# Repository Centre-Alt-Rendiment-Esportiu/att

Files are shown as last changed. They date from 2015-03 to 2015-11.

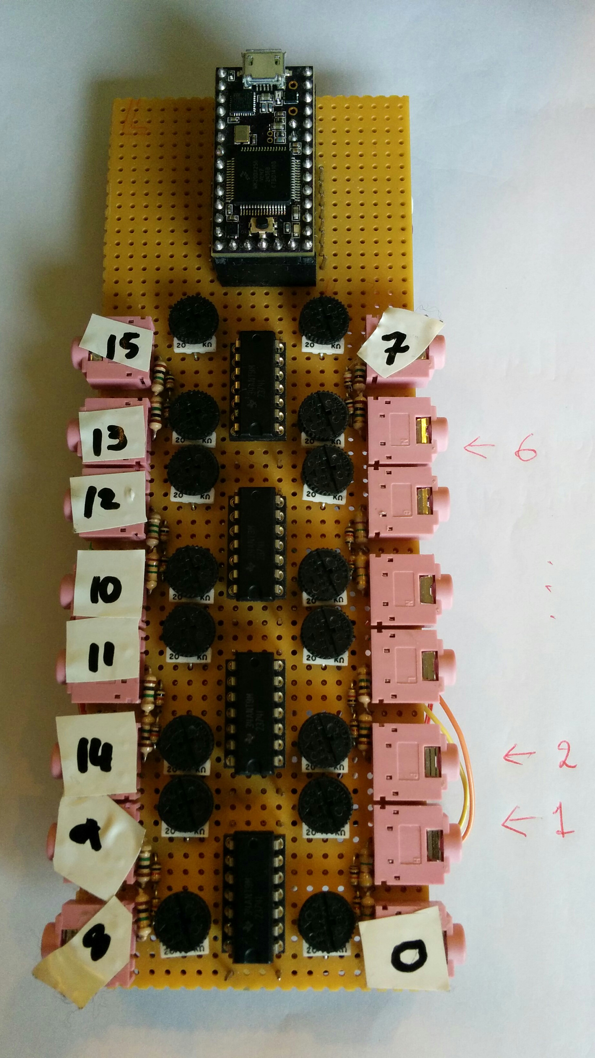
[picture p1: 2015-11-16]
docs/IMG_20151008_105158.jpg

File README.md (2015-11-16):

# Augmented Tennis Table

Augmented Tennis Table is a redesign/fork of PingPong++, a 1998 project of the Tangible Media Group that augmented a pingpong table with ball sensing and interactive projection. This repository contains all the files necessary to setup and run PingPong++.
The propose of this next step of Augmented Table Tennis is to approach it to high performance with specific needs of coaches and training demand based on the EU EXPERIMEDIA Project

* Explore how technology can enhance professional training in table tennis.
* Discover what kind of information is meaningful or too subtle to be directly detected.
* Design a prototype of a system which enables augmented feedback to both elite players and coaches.
*Test it and find requirements for a further version of the system

The experiment provides an automatic notation analysis system for table tennis based on the capture of the bouncing of the ball on the table through sound or vibration. The data obtained from the bouncing location and time is shown projected on the same table and/or a second screen. Statistics, game zones, accuracy, flight time or winning points, can be shown in real-time or after the game to analyse what happened. All the team can be involved in the discussion—athletes, coaches and technical and scientific staff—to help the process to be more efficient.
The way the data can be analysed will change forever the point of view of discussing the game of table tennis.

The experiment used focus group’s to co-create three basic scenarios where the technology could be applied:

* Target training:the scenario has two players (or one player and one assistant) where the trainee has to practice a particular kind of stroke returning the ball in a specific area for a certain amount of times. The area, the number of times and the repetitions of the exercise are set by the assistant. At the end of each repetition, information about the practice was shown on the table and on the screen. The stakeholder required to display a percentage of success, coded with a specific colour. The motivation behind this scenario is to quantify the precision of the player.
* Service Training: the scenario has the presence of one player, practicing the service. The system displays the hits on the table with a relative ID to show the order and the time differences between the bounces on the screen. The trainer sets the number of services to be practiced. The scenario has the goals of representing exactly where the ball is bouncing (difficult to be seen from the player perspective) and shorten the time between the first two bounces. The coach wants also to use it to experiment a hypothesis that he elaborated about associating different time differences according the kind of spin applied.
* Rally Point Patterns: the players play a rally (one point) and the system shows who wins it, and using lines and circles it should represent the situation of the point just played. It was agreed to use a gradient scale to colour the lines to code the time of the hits (from cold colours for older hits till warm colours for the recent ones). The goal of the scenario is to try to represent the gameplay of the players and make post-game analysis.

This first pilot opens new opportunities to share this information with TV in case of Live events or through colleagues and team using images and data. The way metadata is projected over the table or thru complementary screen will enhance the information of the game and will become and attractive asset for TV Broadcasting giving a new way of looking at table tennis in major competitions. Statistics, Accuracy rating, game areas or playing tendencies would be shown in teal time or at the end of the rally to give and augmented reality of the game for the spectators.
On the other hand the same capability could be used on the daily training process using this additional information to enrich the discussion between athletes and coaches and scientific staff that at the end of the day will mean increase the benefits on the learning curve of the team and the sport through augmented reality information.

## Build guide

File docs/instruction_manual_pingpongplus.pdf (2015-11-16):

# PingPong++

## Instruction Manual

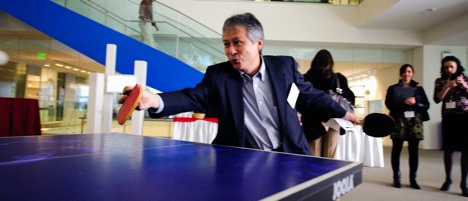
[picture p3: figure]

## Contents

0. Introduction | 3
0.1 Required Materials | 3
0.2 Software Requirements | 3
0.3 Technical Overview | 4
1. Hit Detection Circuitry | 5
1.1 Theory | 5
1.2 Parts | 5
1.3 Piezo Preparation | 6
1.4 Board Fabrication | 7
Installation | 7
2.1 Projector | 7
2.2 Table | 7

2.3 Connections | 8
2.4 Arduino | 8
3. Calibration | 10
4. Running | 12
4.1 Opening Koi Pond | 13
4.2 Present Mode | 13
4.3 Run Mode | 14

## 0. Introduction

PingPong++ is a ping pong table with projected visualizations that respond to locations of ball hits. Based on PingPongPlus, a Tangible Media Group project from 1998, PingPong++ was redesigned by Xiao Xiao and Michael Bernstein in spring 2010.

This document provides instructions for augmenting any standard ping pong table into PingPong++.

### 0.1 Required Materials

The following materials are necessary for PingPong++. The hit detection board and its parts are detailed in Section 1. Specific parts that we used in our installation are given in parentheses

- PingPong table
- Our custom circuit board (see Section 1)
- Arduino board (Decimila, Duemilanove or Uno.
- From Sparkfun: http://www.sparkfun.com/products/11021)
- Computer (Mac mini running OS X 10.6 Snow Leopard)
- USB cord to connect Arduino to computer
- Projector (Hitachi short throw CP-A100 placed on a pedestal)
- Gaffer tape to attach sensors to table

### 0.2 Software Requirements

To run PingPong++, you will need to install the following:

Image: Arduino (left); Gaffer tape (middle); Our projector (right)

- Arduino
- Processing
- Python 2.6
- serial, re, math, random, numpy, and scipy libraries for Python

The PongPong++ software package will include the following
- pingpongplusplus.ino (the Arduino file in the pingpongplusplus folder)
- koi pond (Processing visualization)
- calibration (Processing visualization to help with calibration)
- training.py (Python program to for calibration calculations)

### 0.3 Technical Overview

PingPong++ detects locations of hits on the table using 4 piezoelectric buzzers taped to the underside of each side of the table. Timing differences between pairs of piezo elements are used to calculate where the ball hit.

Our circuit conditions the signal from the piezos, which allows the Arduino board connected to the computer to calculate timing differences. These timing differences are then passed to a Processing visualization running on the computer via the serial port. The Processing visualization is projected on the table.

Image: A piezo buzzer

## 1. Hit Detection Circuitry

You will need to build a copy of our custom circuit for hit detection. Though we recommend using our PCB to simplify the process, We have used a breadboarded circuit and will provide instructions for those who prefer to build one.

### 1.1 Theory

The image below shows diagram of the circuit with capacitor and resistor values. The board includes 8 of this circuit, one for each piezo. The circuit works by first amplifying the piezo signal time 20. It then rectifies the signal so that the first “peaking” of the signal sets of the comparator to trigger a hit.

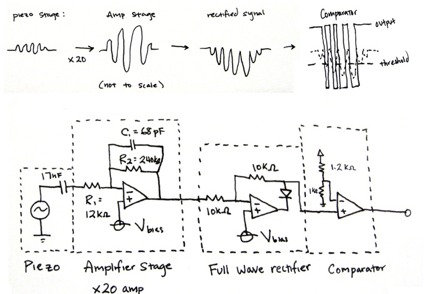
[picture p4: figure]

### 1.2 Parts

Through-hole components are given for breadboarding. Surface mount components are given for the packaging used in our PCB design.

- 8 piezo buzzers
- http://search.digikey.com/scripts/DkSearch/dksus.dll?Detail&name=102-1127-ND
- 8 audio jacks (PCB only) (http://search.digikey.com/scripts/DkSearch/dksus.dll?Detail&name=102-1127-ND)
- http://www.sparkfun.com/products/8032 (http://search.digikey.com/scripts/DkSearch/dksus.dll?Detail&name=102-1127-ND)
- 8 audio cords (PCB only) (http://search.digikey.com/scripts/DkSearch/dksus.dll?Detail&name=102-1127-ND)
- http://www.sparkfun.com/products/8566

- 8 68uF ceramic capacitors
- http://search.digikey.com/scripts/DkSearch/dksus.dll?Detail&name=478-1314-2-ND (surface mount)
- 6 TLV2374 Op-amps
- http://search.digikey.com/scripts/DkSearch/dksus.dll?Detail&name=296-12221-5-ND (through hole)
- http://search.digikey.com/scripts/DkSearch/dksus.dll?Detail&name=296-11967-1-ND (surface mount)
- 8 diodes 1N4148
- http://search.digikey.com/scripts/DkSearch/dksus.dll?Detail&name=1N4148FS-ND (through hole)
- http://search.digikey.com/scripts/DkSearch/dksus.dll?Detail&name=1N4148WTCT-ND (surface mount)
- 18 10 K-Ohm, 1% tolerance resistors (1% tolerance important)
- http://search.digikey.com/scripts/DkSearch/dksus.dll?Detail&name=PPC10.0KYCT-ND (through hole)
- http://search.digikey.com/scripts/DkSearch/dksus.dll?Detail&name=P10.0KCCT-ND (surface mount)
- 8 12 K-Ohm resistors
- http://search.digikey.com/scripts/DkSearch/dksus.dll?Detail&name=P12KBACT-ND (through hole)
- http://search.digikey.com/scripts/DkSearch/dksus.dll?Detail&name=P12KADCT-ND (surface mount)
- 8 240 K-Ohm resistors
- http://search.digikey.com/scripts/DkSearch/dksus.dll?Detail&name=PPCQJ240KCT-ND (through hole)
- http://search.digikey.com/scripts/DkSearch/dksus.dll?Detail&name=P240KACT-ND (surface mount)
- 1 1.2 K-Ohm resistor
- http://search.digikey.com/scripts/DkSearch/dksus.dll?Detail&name=P1.2KBACT-ND (through hole)
- http://search.digikey.com/scripts/DkSearch/dksus.dll?Detail&name=P1.2KACT-ND (surface mount)
- 1 1 K-Ohm resistor
- http://search.digikey.com/scripts/DkSearch/dksus.dll?Detail&name=PPC1.0KW-1CT-ND (through hole)
- http://search.digikey.com/scripts/DkSearch/dksus.dll?Detail&name=541-1.0KACT-ND (surface mount)
- Male headers

### 1.3 Piezo Preparation

The piezos must be prepared so that they can connect to the board. For the breadboard, the two ends of the piezos can simply be soldered to two pieces of wires between 3-6 feet long.

For the PCB, each piezo must connect to one end of an audio cable. To do so, cut off the audio jack from one end and strip the cable to expose the wires within. Solder the red wire of the piezo to the red and white wires in the cable and the black wire of the piezo to the yellow wire in the cable.

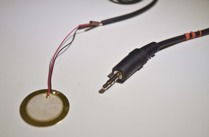
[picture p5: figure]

### 1.4 Board Fabrication

Here is an image of the board with one piezo plugged in.

## Installation

### 2.1 Projector

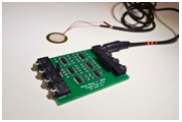
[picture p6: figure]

Our Hitachi projector is placed on a stand 5-feet (1.52m) tall so that it projects down onto the ping pong table. The distance between the stand and the table is about 3-feet but will need to be adjusted for specific situations.

Connect the projector to the computer and run the Calibration program in Processing. Position the projector such that the gray area of the program covers the entire ping pong table. The screen resolution of the computer may have to be adjusted for this.

### 2.2 Table

We attached piezos to the underside of the table using gaffer tape. 4 piezos are placed on each side in the configuration described in the figure. The piezo cables can be taped to the bottom of the table without interfering with the sensing and should be to avoid clutter. We ran the cables to one side of the table and attached them to legs of the table as in the image.

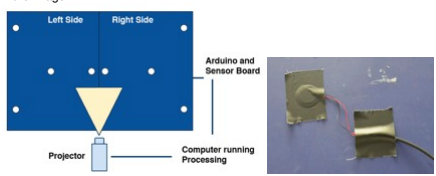
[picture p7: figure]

### 2.3 Connections

- Plug the sensor board into the Arduino according to the image
- Plug the 4 audio cables on the two sides of the table to the audio jacks on the two sides of the board. Make sure the left side and right side of the piezos and of the board match. Left and right are defined by the system configuration image.
- Connect the Arduino board and the computer with the USB cable

### 2.4 Arduino

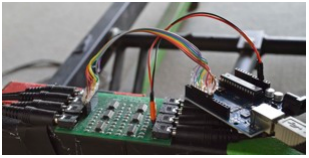
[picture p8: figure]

We need to verify that Arduino is receiving data from serial with the following steps. Your Arduino should be connected to your computer via USB when you do this.

1. Open the Arduino program
2. Go to Tools > Board and make sure the correct Arduino board is selected. Here weʼre using an Arduino UNO

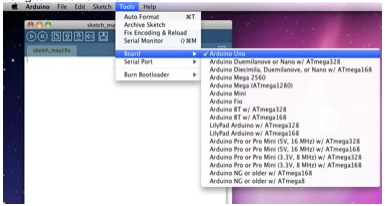
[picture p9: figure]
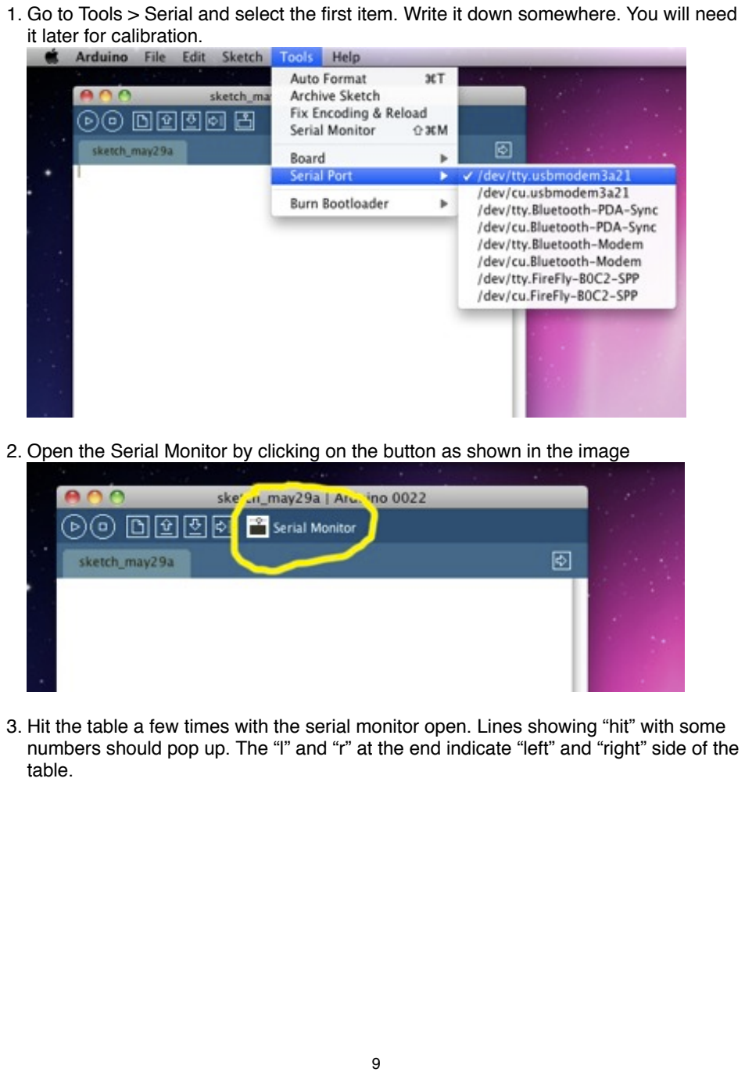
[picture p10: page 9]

1. Go to Tools > Serial and select the first item. Write it down somewhere. You will need it later for calibration.
2. Open the Serial Monitor by clicking on the button as shown in the image
3. Hit the table a few times with the serial monitor open. Lines showing “hit” with some numbers should pop up. The “l” and “r” at the end indicate “left” and “right” side of the table.

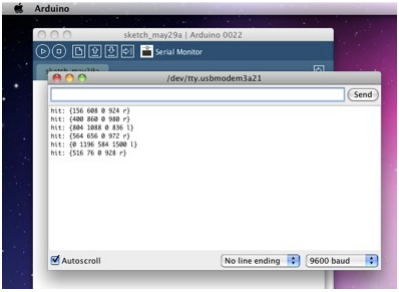
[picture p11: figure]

If everything works according to described, your computer is now receiving hit data from the Arduino! If nothing show up on the serial monitor when you hit the table, something is probably not connected properly.

## 3. Calibration

The calibration works by asking you to drop the ball at 20 points on each side of the table. The Calibration visualization shows you where to drop the balls.

Open Processing and run the Calibration visualization. See section 4 for instructions on how to run a program in Processing.

On another screen, you will run the Python program training.py to calibrate. Before running it, open it in a text editor program like TextEdit and change the port to what you copied from the Serial setting in Arduino. In our case, we are going to replace the highlighted line in the image with the following:

PORT = '/dev/tty.usbmodem3a21' # FOR MAC

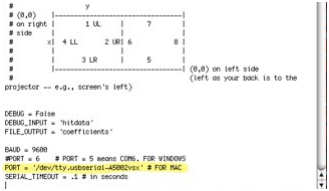
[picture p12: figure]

Now, open a terminal window and cd to where training.py is (we have it on the desktop). Type python2.6 training.py to run it.

It will ask you whether you want to calibrate the left, right or both sides. Press the key for your selection and press enter. Then follow the directions the script gives you.

For each point, it will ask you to drop the ball 5 times. For best results, vary how hard you drop the ball for each of the 5 drops. Start with light drops and gradually increase the strength it hits the table.
At the end of 5 repetitions, it will ask whether you want to do that point again or move on. If your ball accidentally bounced in a wrong place, you can press “r” to repeat that point. Otherwise, hit enter to continue.

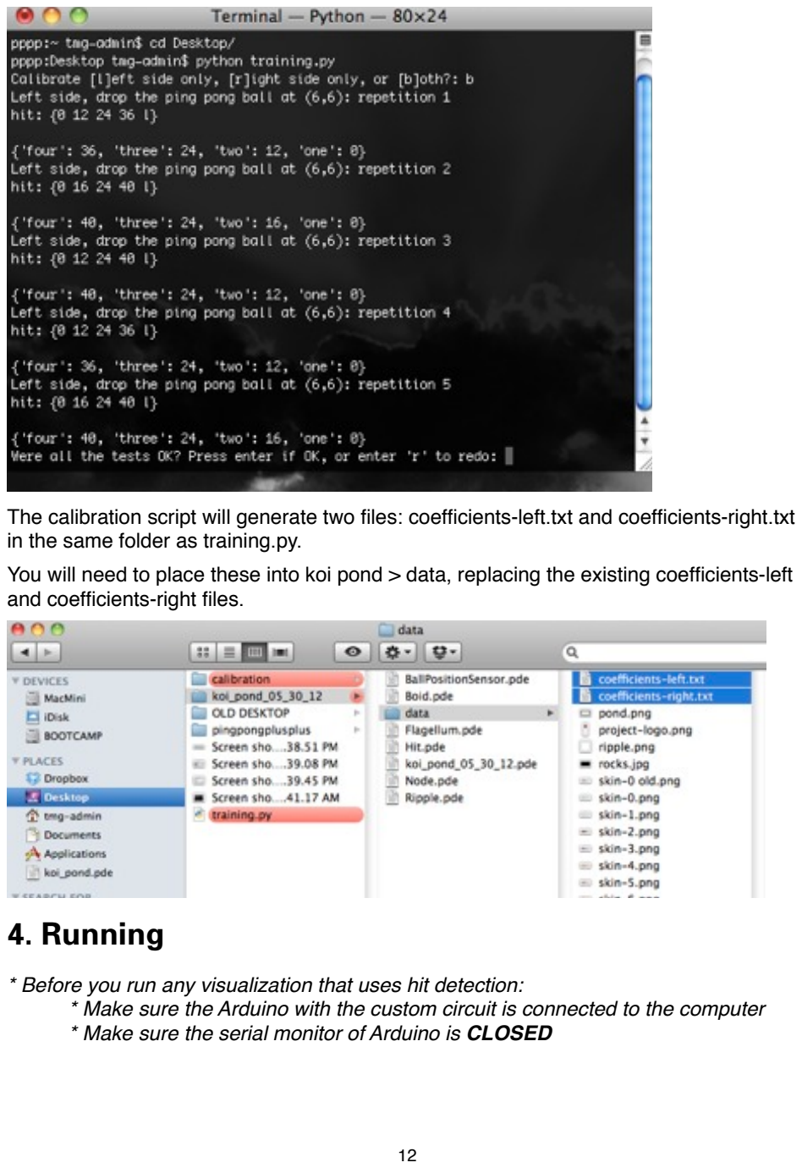
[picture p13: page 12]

The calibration script will generate two files: coefficients-left.txt and coefficients-right.txt in the same folder as training.py.
You will need to place these into koi pond > data, replacing the existing coefficients-left and coefficients-right files.

## 4. Running

* Before you run any visualization that uses hit detection:
* Make sure the Arduino with the custom circuit is connected to the computer * Make sure the serial monitor of Arduino is CLOSED

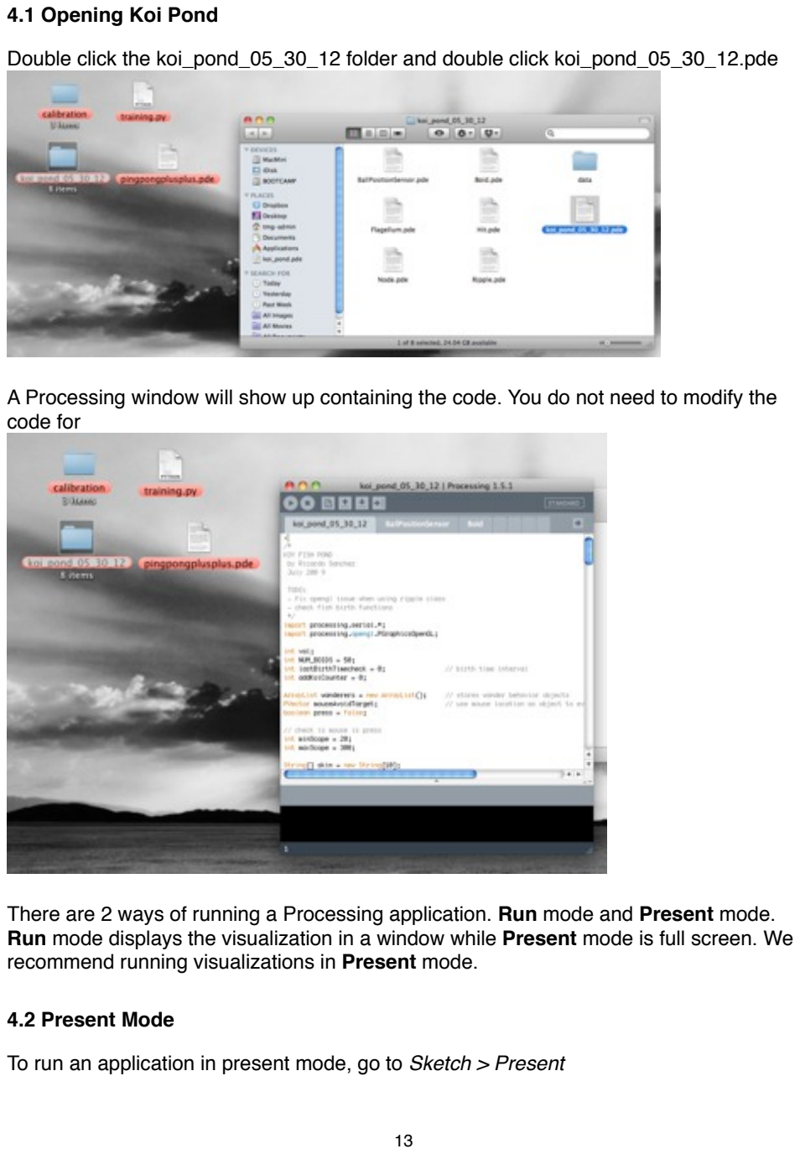
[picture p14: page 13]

### 4.1 Opening Koi Pond

Double click the koi_pond_05_30_12 folder and double click koi_pond_05_30_12.pde

A Processing window will show up containing the code. You do not need to modify the code for

There are 2 ways of running a Processing application. Run mode and Present mode. Run mode displays the visualization in a window while Present mode is full screen. We recommend running visualizations in Present mode.

### 4.2 Present Mode

To run an application in present mode, go to Sketch > Present

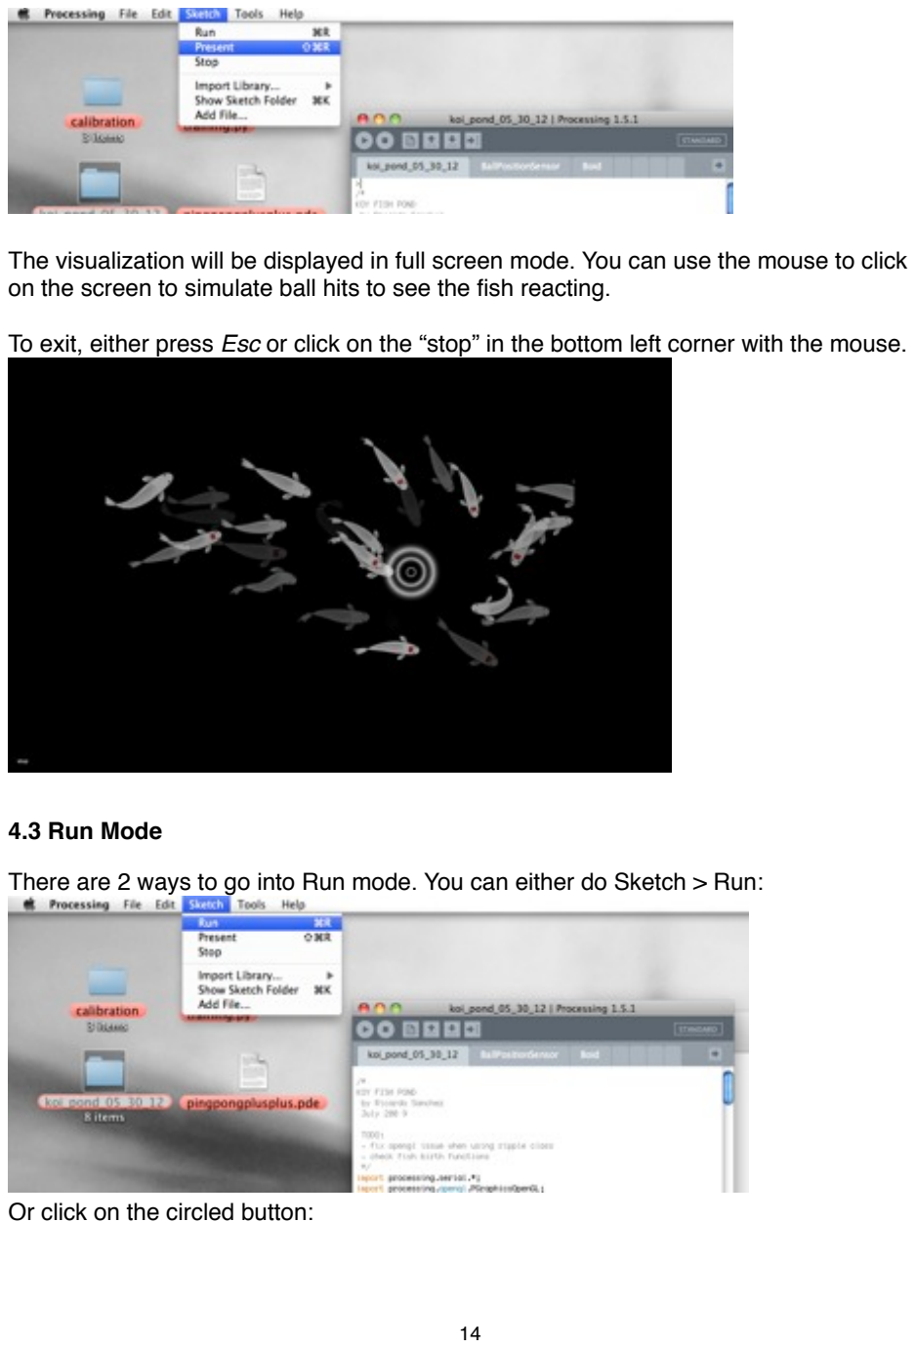
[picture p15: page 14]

The visualization will be displayed in full screen mode. You can use the mouse to click on the screen to simulate ball hits to see the fish reacting.

To exit, either press Esc or click on the “stop” in the bottom left corner with the mouse.

### 4.3 Run Mode

There are 2 ways to go into Run mode. You can either do Sketch > Run:

Or click on the circled button:

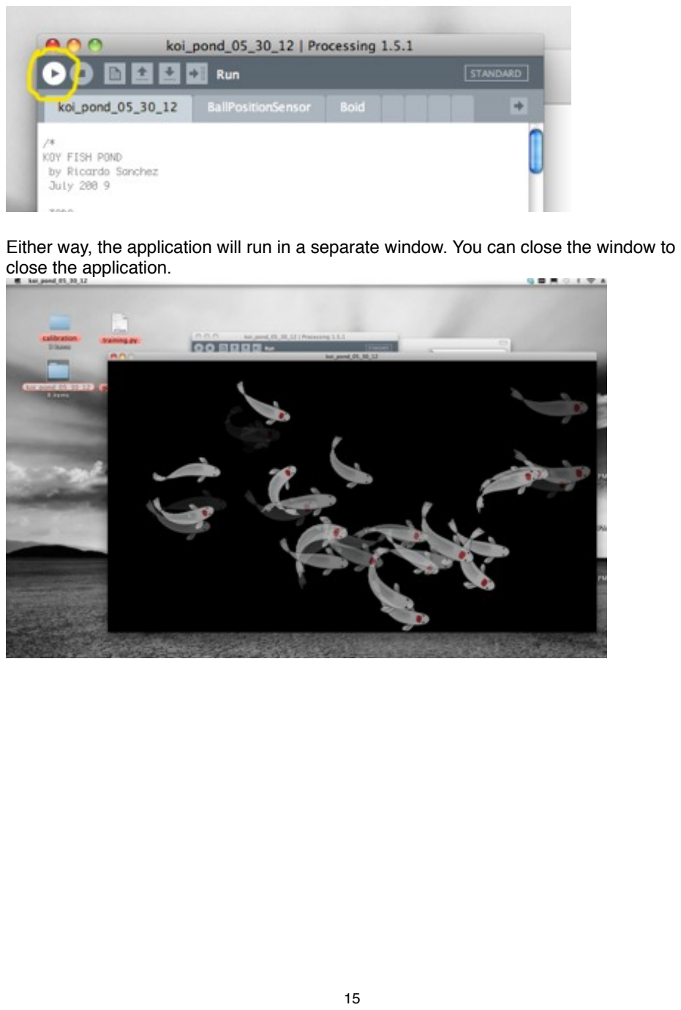
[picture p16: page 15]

Either way, the application will run in a separate window. You can close the window to close the application.

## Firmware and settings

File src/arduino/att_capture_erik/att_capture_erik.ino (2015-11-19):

/*
 * Original PingPong++
 * -------------
 * By Michael Bernstein (msbernst@mit.edu) and Xiao Xiao (x_x@mit.edu)
 *
 * Augmented Table Tennis
 * -------------
 * By Andrea Amodeo and Erik Einebrant
 */
 
// Constants
const int THRESHOLD = 30;
const int SENSOR_COUNT = 7;
//NOTE: There are 8 but for the time being we only use 7 as this is more compatible with available software

struct Hit {
  unsigned long timings[SENSOR_COUNT];
  int volumes[SENSOR_COUNT];
  
  unsigned long startTime;
  char side;
  boolean reported;  // have we sent it off via serial yet?
};

/*struct Hit {
  unsigned long upperLeft;
  unsigned long upperRight;
  unsigned long lowerLeft;
  unsigned long lowerRight;
  unsigned long centerLeft;
  unsigned long centerUp;
  unsigned long centerRight;
  unsigned long startTime;
  char side;
  boolean reported;  // have we sent it off via serial yet?
};*/

//Pin mapping of Teensy
int rightPins[] = {
  A8, A9, A10, A11, A12, A13, A14, /*A15*/}; // clockwise from top left
int leftPins[] = {
  A0, A1, A2, A3, A4, A5, A6, /*A7*/}; // clockwise from top left

const unsigned long NO_RECORD = -1;
const unsigned long TIMEOUT_BETWEEN_HITS = 300000; // in millis
const char LEFT = 'l';
const char RIGHT = 'r';

Hit curHit = { 
  NO_RECORD, NO_RECORD, NO_RECORD, NO_RECORD, NO_RECORD, NO_RECORD, NO_RECORD, NO_RECORD, LEFT, false};

void setup() {
  Serial.begin(115200);
}

/*void setup() {
  Serial.begin(115200);
  for (int i = 0; i < 7; i++) {
    int pinNumber = leftPins[i];
    pinMode(pinNumber, INPUT);
    pinNumber = rightPins[i];
    pinMode(pinNumber, INPUT);
  }
}*/

void loop() {
  //delay(5);
  readPins(leftPins, LEFT);
  readPins(rightPins, RIGHT);
  
  //Serial.println(curHit.volumes[0]);
  
  if (isCompleteHit(&curHit) && !curHit.reported) {
    // print the current hit status
    Serial.print("hit: {");
    for(int i = 0; i < SENSOR_COUNT; i++){
      Serial.print(curHit.timings[i]);
      /*Serial.print(":");
      Serial.print(curHit.volumes[i]);*/
      Serial.print(" ");
    }
    Serial.print(curHit.side);
    Serial.println("}");
    
    curHit.reported = true;
  }
  
  if(hitTimedOut()) {
    // create a new hit
    Hit newHit;
    for(int i = 0; i < SENSOR_COUNT; i++){
      newHit.timings[i] = NO_RECORD;
      newHit.volumes[i] = NO_RECORD;
    }
    
    newHit.side = LEFT;
    newHit.startTime = NO_RECORD;
    newHit.reported = false;
    
    curHit = newHit;
  }
}

/*void loop() {
  readPins(leftPins, LEFT);
  readPins(rightPins, RIGHT);
  
  if (isCompleteHit(&curHit) && !curHit.reported) {
    // print the current hit status
    Serial.print("hit: {");
    Serial.print(curHit.upperLeft);
    Serial.print(" ");
    Serial.print(curHit.upperRight);
    Serial.print(" ");
    Serial.print(curHit.lowerRight);
    Serial.print(" ");
    Serial.print(curHit.lowerLeft);
    Serial.print(" ");
    Serial.print(curHit.centerLeft);
    Serial.print(" ");
    Serial.print(curHit.centerUp);
    Serial.print(" ");
    Serial.print(curHit.centerRight);
    Serial.print(" ");
    Serial.print(curHit.side);
    Serial.println("}");
    
    curHit.reported = true;
  }

  if (hitTimedOut()) {
    // create a new hit
    Hit newHit;
    newHit.upperLeft = newHit.upperRight = newHit.lowerLeft = newHit.lowerRight = newHit.centerLeft = newHit.centerUp = newHit.centerRight = NO_RECORD;
    newHit.side = LEFT;
    newHit.startTime = NO_RECORD;
    newHit.reported = false;
    
    curHit = newHit;
  }
}*/

/*
 * For the list of one sides pins, see if any of them is detecting an analog reading above the threshold
 * and if so, report a hit with side and detection time
 */
void readPins(int* pinList, char curSide) {
  for (int i = 0; i < SENSOR_COUNT; i++) {
    int pinNumber = pinList[i];
    int pinValue = analogRead(pinNumber);
    //Serial.println(pinValue);
    if (pinValue >= THRESHOLD) {
      unsigned long detectionTime = micros();
      if (curHit.startTime == NO_RECORD) {
        curHit.startTime = detectionTime;
        curHit.side = curSide;
      }
      // add this data to the existing hit
      updateCorner(pinNumber, curSide, detectionTime, pinValue, pinList);
     }
  }
}

/*
 * Looks at each pin on the side to see if it is LOW (e.g., registered a hit) 
 * and updates the Hit data structure if so.
 */
/*void readPins(int* pinList, char curSide) {
  for (int i = 0; i < 7; i++) {
    int pinNumber = pinList[i];
    int pinValue = digitalRead(pinNumber);
    if (pinValue == LOW) {
      unsigned long detectionTime = micros();
      if (curHit.startTime == NO_RECORD) {
        curHit.startTime = detectionTime;
        curHit.side = curSide;
      }
      // add this data to the existing hit
      updateCorner(pinNumber, curSide, detectionTime, pinList);
     }
  }
}*/

/*
 * Updates the current hit data structure in the correct corner, given the pin number
 */
void updateCorner(int pinNumber, char curSide, unsigned long detectionTime, int pinValue, int* sidePins){
  for(int i = 0; i < SENSOR_COUNT; i++){
    if(pinNumber == sidePins[i] && curHit.timings[i] == NO_RECORD){
      curHit.timings[i] = detectionTime - curHit.startTime;
      curHit.volumes[i] = pinValue;
    }
  }
}

/*
 * Updates the current hit data structure in the correct corner, given the pin number
 */
/*void updateCorner(int pinNumber, char curSide, unsigned long detectionTime, int* sidePins) {

  if (pinNumber == sidePins[0] && curHit.upperLeft == NO_RECORD) {
    curHit.upperLeft = detectionTime - curHit.startTime;
  }
  else if (pinNumber == sidePins[1] && curHit.upperRight == NO_RECORD) {
    curHit.upperRight = detectionTime - curHit.startTime;
  }
  else if (pinNumber == sidePins[2] && curHit.lowerRight == NO_RECORD) {
    curHit.lowerRight = detectionTime - curHit.startTime;
  }
  else if (pinNumber == sidePins[3] && curHit.lowerLeft == NO_RECORD) {
    curHit.lowerLeft = detectionTime - curHit.startTime;
  }
  else if (pinNumber == sidePins[4] && curHit.centerLeft == NO_RECORD) {
    curHit.centerLeft = detectionTime - curHit.startTime;
  }
  else if (pinNumber == sidePins[5] && curHit.centerUp == NO_RECORD) {
    curHit.centerUp = detectionTime - curHit.startTime;
  }
  else if (pinNumber == sidePins[6] && curHit.centerRight == NO_RECORD) {
    curHit.centerRight = detectionTime - curHit.startTime;
  }
}*/

boolean hitTimedOut() {
  unsigned long time_since = micros() - curHit.startTime;
  boolean timed_out = (time_since >= TIMEOUT_BETWEEN_HITS);
  return (curHit.startTime == NO_RECORD || timed_out);
}

boolean isCompleteHit(struct Hit *hit) {
  boolean isHit = true;
  for(int i = 0; i < SENSOR_COUNT; i++){
    isHit = isHit && hit->timings[i] != NO_RECORD;
  }
  return isHit;
}

/*boolean isCompleteHit(struct Hit *hit) {
  return hit->upperLeft != NO_RECORD && hit->upperRight != NO_RECORD && hit->lowerRight != NO_RECORD && hit->lowerLeft != NO_RECORD && hit->centerLeft != NO_RECORD && hit->centerUp != NO_RECORD && hit->centerRight != NO_RECORD;
}*/

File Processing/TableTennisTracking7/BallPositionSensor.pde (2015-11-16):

 import matrixMath.*;

import processing.serial.*;

class BallPositionSensor {
  boolean debug = false;
  int TABLE_WIDTH = 60;   // inches
  int TABLE_HEIGHT = 54;  // inches
  int SENSOR_COUNT = 7;
  
  Serial arduinoSerial;
  matrixMath mc1_l, mc2_l, mc3_l, mc4_l, mc5_l, mc6_l, mc7_l, mc1_r, mc2_r, mc3_r, mc4_r, mc5_r, mc6_r, mc7_r;
  matrixMath[] mc_l[SENSOR_COUNT];
  matrixMath[] mc_r[SENSOR_COUNT];
  
  BallPositionSensor(PApplet applet, String portName, String coefficientFileLeft, String coefficientFileRight) {
    importCoeffs(coefficientFileLeft, false); // "../../coefficients-left.txt"
    importCoeffs(coefficientFileRight, true); // "../../coefficients-right.txt"
    arduinoSerial = new Serial(applet, portName, 115200);
  }

  void importCoeffs(String coefficientFile, boolean isRightSide) {
    String[] coeffs = loadStrings(coefficientFile);
    int sensorSum = 0;
    for(int s = 1; s <= SENSOR_COUNT; s++){
      sensorSum += s;
    }
    
    float[][][] coeffs = new float[SENSOR_COUNT][2][sensorSum];

    /*float[][] coeffs1 = new float[2][sensorSum];
    float[][] coeffs2 = new float[2][sensorSum];
    float[][] coeffs3 = new float[2][sensorSum];
    float[][] coeffs4 = new float[2][sensorSum];
    float[][] coeffs5 = new float[2][sensorSum];
    float[][] coeffs6 = new float[2][sensorSum];
    float[][] coeffs7 = new float[2][sensorSum];*/
    
    for(int i = 0; i < sensorSum; i++){
      for(int s = 0; s < SENSOR_COUNT; s++){
        int curSide = int(s >= SENSOR_COUNT);
        coeffs[s][curSide][i] = float(coeffs[sensorSum * s + i]);
      }
    }
    
    /*for (int i = 0; i < 28; i++) {
      coeffs1[0][i] = float(coeffs[i]);
      coeffs2[0][i] = float(coeffs[sensorSum * 1 + i]);
      coeffs3[0][i] = float(coeffs[sensorSum * 2 + i]);
      coeffs4[0][i] = float(coeffs[sensorSum * 3 + i]);
      coeffs5[0][i] = float(coeffs[sensorSum * 4 + i]);
      coeffs6[0][i] = float(coeffs[sensorSum * 5 + i]);
      coeffs7[0][i] = float(coeffs[sensorSum * 6 + i]);
      
      coeffs1[1][i] = float(coeffs[sensorSum * 7 + i]); 
      coeffs2[1][i] = float(coeffs[sensorSum * 8 + i]);
      coeffs3[1][i] = float(coeffs[sensorSum * 9 + i]);
      coeffs4[1][i] = float(coeffs[sensorSum * 10 + i]);
      coeffs5[1][i] = float(coeffs[sensorSum * 11 + i]);
      coeffs6[1][i] = float(coeffs[sensorSum * 12 + i]);
      coeffs7[1][i] = float(coeffs[sensorSum * 13 + i]);
    }*/
    
    if (isRightSide) {
      for(int i = 0; i < SENSOR_COUNT; i++){
        mc_r[i] = new matrixMath(coeffs[i]);
      }
    } else{
      for(int i = 0; i < SENSOR_COUNT; i++){
        mc_l[i] = new matrixMath(coeffs[i]);
      }
    }
      
    /*if(isRightSide) {
      mc1_r = new matrixMath(coeffs1); 
      mc2_r = new matrixMath(coeffs2);
      mc3_r = new matrixMath(coeffs3);
      mc4_r = new matrixMath(coeffs4);
      mc5_r = new matrixMath(coeffs5);
      mc6_r = new matrixMath(coeffs6);
      mc7_r = new matrixMath(coeffs7);
    }
    else {
      mc1_l = new matrixMath(coeffs1);
      mc2_l = new matrixMath(coeffs2);
      mc3_l = new matrixMath(coeffs3);
      mc4_l = new matrixMath(coeffs4);
      mc5_l = new matrixMath(coeffs5);
      mc6_l = new matrixMath(coeffs6);
      mc7_l = new matrixMath(coeffs7);
    }*/
  }

  Hit readHit() {
     String serialData = null;
     if (debug) {
       if (random(100) <= 1) {
         serialData = "hit: {1908 1120 0 2004 1700 98 200 r}";
       } else if (random(100) <= 1) {
         serialData = "hit: {1544 668 0 1288 1700 569 1200 r}";
       }
       else {
         serialData = null;
       }
     } else if (arduinoSerial.available() > 0) {
       serialData = arduinoSerial.readStringUntil(10);  //10 is character for linefeed
     }  


    if (serialData == null) {
      return null;
    }
    else {
      println(serialData);
      Hit hit = getHit(serialData);
      // 54 x 60
      //println("(" + position.x + ", " + position.y + ")");
      return hit;
    }
  }

  private Hit getHit(String serialData) {
    String[] values = split(serialData, "{");
    String[] timings = split(values[1], " ");
    
    

    float t12 = float(timings[0])-float(timings[1]);
    float t13 = float(timings[0])-float(timings[2]);
    float t14 = float(timings[0])-float(timings[3]);
    float t15 = float(timings[0])-float(timings[4]);
    float t16 = float(timings[0])-float(timings[5]);
    float t17 = float(timings[0])-float(timings[6]);
    float t23 = float(timings[1])-float(timings[2]);
    float t24 = float(timings[1])-float(timings[3]);
    float t25 = float(timings[1])-float(timings[4]);
    float t26 = float(timings[1])-float(timings[5]);
    float t27 = float(timings[1])-float(timings[6]);
    float t34 = float(timings[2])-float(timings[3]);
    float t35 = float(timings[2])-float(timings[4]);
    float t36 = float(timings[2])-float(timings[5]);
    float t37 = float(timings[2])-float(timings[6]);
    float t45 = float(timings[3])-float(timings[4]);
    float t46 = float(timings[3])-float(timings[5]);
    float t47 = float(timings[3])-float(timings[6]);
    float t56 = float(timings[4])-float(timings[5]);
    float t57 = float(timings[4])-float(timings[6]);
    float t67 = float(timings[5])-float(timings[6]);
    /*int first_one = 0;
    int first_two = 0; 
    int first_four = 0;
    if (int(timings[0]) == 0) {
      first_one = 1;
    } else if (int(timings[1]) == 0) {
      first_two = 1;
    } else if (int(timings[3]) == 0) {
      first_four = 1;
    }*/
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

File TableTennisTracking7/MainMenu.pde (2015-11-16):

class MainMenu extends Mode {
  String[] options = new String[3];
  int[][] optionsRects;

  MainMenu() {
    options[0] = "Target Training";
    options[1] = "Service Training";
    options[2] = "Point's Pattern";
  }

  void display() {
    background(0);
    color c = #FFFFFF;
    fill(c);
    PFont verdana100;
    verdana100 = loadFont("Verdana-100.vlw");
    textAlign(CENTER);
    textFont(verdana100);
    text("Table Tennis Tracking", 0, height/2 - 100, width, height);
  }

  void secondDisplay() {
    colorMode(RGB);

    int[][] optionsRects = { 
      {
        computerScreen.width/2-200, 150, 400, 100, 7
      }
      , 
      {
        computerScreen.width/2-200, 320, 400, 100, 7
      }
      , 
      {
        computerScreen.width/2-200, 490, 400, 100, 7
      }
    };

    computerScreen.background(0);
    computerScreen.fill(255);
    PFont verdana60 = loadFont("Verdana-60.vlw");
    PFont verdana48 = loadFont("Verdana-48.vlw");

    computerScreen.textAlign(CENTER);
    computerScreen.textFont(verdana60);
    computerScreen.text("Select the Training", 0, 50, computerScreen.width, computerScreen.height);

    computerScreen.textFont(verdana48);
    computerScreen.stroke(255);
    computerScreen.noFill();
    for (int i=0; i<3; i++) {
      computerScreen.rect(optionsRects[i][0], optionsRects[i][1], optionsRects[i][2], optionsRects[i][3], optionsRects[i][4]);
      computerScreen.text(options[i], optionsRects[i][0], optionsRects[i][1]+30, optionsRects[i][2], optionsRects[i][3]);
    }
    for (int i=0; i<3; i++) { // highlights the buttons
      if ((computerScreen.mouseX > optionsRects[i][0] && computerScreen.mouseX < optionsRects[i][0] + optionsRects[i][2]) && 
        (computerScreen.mouseY > optionsRects[i][1] && computerScreen.mouseY < optionsRects[i][1] + optionsRects[i][3])) {
        computerScreen.stroke(255);
        computerScreen.fill(#8E8B89);
        computerScreen.rect(optionsRects[i][0], optionsRects[i][1], optionsRects[i][2], optionsRects[i][3], optionsRects[i][4]);
        computerScreen.fill(255);
        computerScreen.text(options[i], optionsRects[i][0], optionsRects[i][1]+30, optionsRects[i][2], optionsRects[i][3]);
      }
    }
  }

  void chooseOption(int index) {
    mode = index;
    background(0);
    computerScreen.background(0);
  }

  void onHit(Hit hit) {
  }

  void onMouseClicked() {
    int[][] optionsRects = { 
      {
        computerScreen.width/2-200, 150, 400, 150, 7
      }
      , 
      {
        computerScreen.width/2-200, 320, 400, 150, 7
      }
      , 
      {
        computerScreen.width/2-200, 490, 400, 150, 7
      }
    };
    for (int i=0; i<3; i++) { // checks what is the selected menu item and loads the relative screen
      if ((computerScreen.mouseX > optionsRects[i][0] && computerScreen.mouseX < optionsRects[i][0] + optionsRects[i][2]) && 
        (computerScreen.mouseY > optionsRects[i][1] && computerScreen.mouseY < optionsRects[i][1] + optionsRects[i][3])) {
        chooseOption(i+1);
      }
    }
  }
}

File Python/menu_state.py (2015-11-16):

import serial
import re
from math import fabs
import random as python_random

import pygame

class MenuState:
	font = None

	curOption = 0
	menuOptions = [
		'Projection Surface',
		'Sensor Position',
		'Sensor Matrix',
		'Track Ball']

	def __init__(self, pygame):
		screen = pygame.display.get_surface()

		# Fill background
		background = pygame.Surface(screen.get_size())
		background = background.convert()
		background.fill((250, 250, 250))

		# Display some text
		self.font = pygame.font.Font(None, 36)

	def update(self, setState, isPressed, pygame):
		screen = pygame.display.get_surface()

		if isPressed(pygame.K_DOWN):
			self.curOption = (self.curOption + 1) % len(self.menuOptions)

		if isPressed(pygame.K_UP):
			self.curOption = (self.curOption + len(self.menuOptions) - 1) % len(self.menuOptions)

		if isPressed(pygame.K_RETURN):
			setState(self.curOption + 1)

		for i in range(len(self.menuOptions)):
			if not(i == self.curOption):
				text = self.font.render(self.menuOptions[i], 1, (80, 80, 80))
			else:
				text = self.font.render(self.menuOptions[i], 1, (0, 0, 0))
			screen.blit(text, (5, 10 + 25 * i))

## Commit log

2015-03-26 Initial Commit from ICT and github submodule
    [New Piezo.fzz, site.cfg]
2015-11-19 Found bug in flash software running old digital read solution when the new box give analog signals (for analog read). Added the updates as its own arduino-project, ATT_flash, for the sake of simplici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
2016-01-27 Old project moved
    [New Piezo (Konfliktkopia för Erik Einebrant 2015-06-09).fzz, New Piezo.fzz, site.cfg]
2016-02-21 Solving Issue with both sides lecture: [CAR] - [Arduino - Driver] - Quan lectura 2 bandes simultania, verificar detecció Dreta/Esquerra
    [att_capture_base.ino]
2016-02-28 Short Service added. Some fixes
    [serial_port.py, serial_reader.py]
2016-02-28 Timeout Thread added
2016-02-29 refactor. MVC implementation. Fixes on short service
    [serial_reader.py]
2017-03-07 Create testing environment (#4)
    * Created Testing classes
    * Created testing environment
    * Fixed error formulas
    * Deleted tableDetector file
    [main.py]
2017-03-08 Improved tracking with background subtraction (#5)
    * Done background substraction easy algorithm
    * Fixed tests
    * Improved background subtraction algorithm
    * Reordered method
    [main.py]
2017-03-27 Create basic scoreboard (#7)
    * Restructured classes for scoreboard
    * Finished first version of scoreboard
    * Moved first frame logic to PingPongApp
    * Improved algorithm with left-right table side detection
    * Ups
2017-04-06 Made search first inside table then outside (#8)
    * Improved color tracking and made search first inside table, then outside
    * Added BlobDetection for ball tracking
    * Trying...
    * Resized frame for optimization
    * Last refactorings
    * Deleted unnecessary PeopleDetector
2017-05-09 PaintHistory refactoring (#14)
    * [TO BE FIXED] Made frame buffer logic
    * Created frame buffer and refactored Extrapolator+BounceDetector
    * Left out a constructor parameter
    * Done refactoring
2017-05-29 Added Camera Calibration script to correct camera distortion (#18)
2017-06-03 Undistorted camera (#19)
